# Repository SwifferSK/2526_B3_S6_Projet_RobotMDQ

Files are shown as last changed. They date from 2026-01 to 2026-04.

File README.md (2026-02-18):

<!-- ===================================================== -->
<!--                        HERO                            -->
<!-- ===================================================== -->

<p align="center">
  
</p>

<p align="center">
  
</p>

<!-- ===================================================== -->
<!--                       BADGES                           -->
<!-- ===================================================== -->

<p align="center">
  <a href="https://discord.gg/eySWAjkd">
    
  </a>

  <a href="https://www.youtube.com">
    
  </a>
</p>

<p align="center">
  

  <a href="https://www.kicad.org">
    
  </a>

  

  <a href="https://www.raspberrypi.com">
    
  </a>
</p>

---
## 🧭 Menu
- [Présentation](#présentation)
- [Fonctionnalités](#fonctionnalités)
- [Structure du dépôt](#structure-du-dépôt-branches)
- [Architecture](#architecture)
- [Hardware](#hardware)
- [Dashboard](#dashboard)
- [Demo](#demo)
- [Équipe](#équipe)

---

## Présentation

Ce projet consiste à concevoir un **robot autonome bipède** capable de suivre une ligne tracée au sol.        

Le robot utilise ses **capteurs** pour comprendre sa position et ajuste en permanence ses **moteurs** afin de ne pas tomber pendant le déplacement.

L’ensemble du système est contrôlé par une **Raspberry Pi Zero 2W**, qui traite les informations et prend les décisions en temps réel.

---

## Fonctionnalités
<div align="center">
  <table align="center" cellspacing="0" cellpadding="14">
    <tr>
      <td width="300" align="center" valign="top">
        <h3>🛤️ Suivi de ligne</h3>
        <p>
          Détection du trajet via des photorésistances/ligne<br/>
          Seuils + calibration<br/>
          Lecture analogique via ADC
        </p>
      </td>
      <td width="300" align="center" valign="top">
        <h3>🧠 Stabilisation </h3>
        <p>
          IMU (acc + gyro)<br/>
          Filtrage <br/>
          Donnée envoyer en I2C au MCU<br/>
        </p>
      </td>
      <td width="300" align="center" valign="top">
        <h3>⚙️ Contrôle</h3>
        <p>
          Boucle temps réel (PID prévu)<br/>
          Commande moteurs fluide<br/>
          Sécurités (tilt / cutoff)
        </p>
      </td>
    </tr>
  </table>
</div>

---
##  Structure du Dépôt (Branches)

Le projet est organisé de manière modulaire. La branche `main` contient le système complet, tandis que les branches de développement permettent de tester chaque composant indépendamment :

* **`main`** : Schéma électrique complet,
* **`Kicad_RPI_IMU`** :Schéma électrique de l'**IMU LSM6DSOX**.
* **`Kicad_MCP3208`** : Schéma électrique du **MCP3208** et lecture des photorésistances pour la détection de ligne.
* **`Kicad_TMC2225`** : Schéma électrique de **TMC2225** pour le contrôle des moteurs pas à pas. .
* **`merged-code`** : Fusion des 3 firmwares.
* **`Firmware_MCP3208`** : Firmmware du **MCP3208**.
* **`Firmware_LSM6DSOX`** :Firmmware du l'**IMU LSM6DSOX**.
* **`Firmware_TMC2225`** : Firmmware du **TMC2225** .
---

## Architecture

<div align="center">

  <tr>
    <td width="540" valign="top">
      <h3 align="center">🔌 Chaîne matérielle</h3>
      <p align="center">
        Capteurs optiques → <b>MCP3208 (ADC)</b><br/>
        IMU → <b>I2C/SPI</b> → <b>Raspberry Pi Zero 2W</b><br/>
        RPi → <b>GPIO</b> → <b>TMC2225</b> → Moteurs pas à pas
      </p>
    </td>
    <td width="540" valign="top">
      <h3 align="center">🧠 Chaîne de contrôle</h3>
      <p align="center">
        Acquisition → Filtrage → Estimation<br/>
        Contrôle (PID) → Commande moteurs<br/>
      </p>
    </td>
  </tr>

</div>

---

## Hardware

<div align="center">

<table align="center">
  <tr>
    <th align="left">Composant</th>
    <th align="left">Rôle</th>
    <th align="left">Interface</th>
  </tr>
  <tr>
    <td><b>Raspberry Pi Zero 2W</b></td>
    <td>Contrôleur principal</td>
    <td>GPIO / SPI / I2C</td>
  </tr>
  <tr>
    <td><b>LSM6DSOX</b></td>
    <td>IMU (acc + gyro)</td>
    <td>I2C / SPI</td>
  </tr>
  <tr>
    <td><b>MCP3208</b></td>
    <td>Convertisseur ADC</td>
    <td>SPI</td>
  </tr>
  <tr>
    <td><b>TMC2225 (x2)</b></td>
    <td>Drivers moteurs pas à pas</td>
    <td>STEP / DIR</td>
  </tr>
  <tr>
    <td><b>Capteurs optiques</b></td>
    <td>Détection de ligne</td>
    <td>Analogique</td>
  </tr>
</table>

</div>

---

## Dashboard
<div align="center">

<p align="center">
  <a href="https://github.com/SwifferSK/2526_B3_S6_Projet_RobotMDQ/issues">
    
  </a>
  <a href="https://github.com/SwifferSK/2526_B3_S6_Projet_RobotMDQ/commits/main">
    
  </a>
</p>

  </a>
  <a href="https://github.com/SwifferSK/2526_B3_S6_Projet_RobotMDQ/releases">
    
  </a>
  <a href="https://github.com/SwifferSK/2526_B3_S6_Projet_RobotMDQ">
    
  </a>
</p>

<table align="center">
  <tr>
    <td align="center" width="520">
      RepoBeats
    </td>
   
  </tr>
</table>

</div>

---

## Demo

<p align="center">
  
</p>

<p align="center">
  <!-- <img src="assets/demo.gif" width="820" alt="Demo" /> -->
</p>

---

## Équipe

<p align="center">
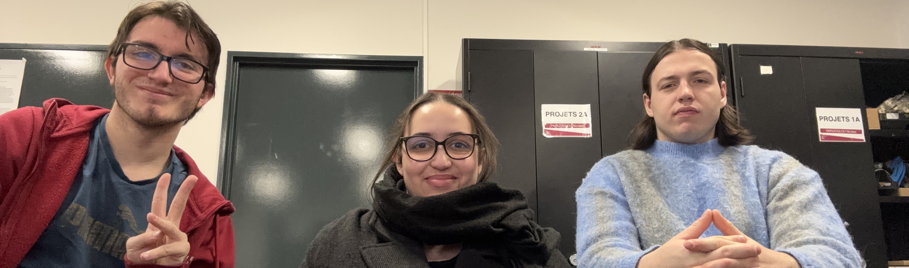
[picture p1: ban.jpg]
  
</p>
<p align="center">
  <b> Damien Theas • Manel Benboujemaa  • Quentin Bechler</b><br/>
  <sub>Bachelor ENSEA — Robotique • Design matériel</sub>
</p>

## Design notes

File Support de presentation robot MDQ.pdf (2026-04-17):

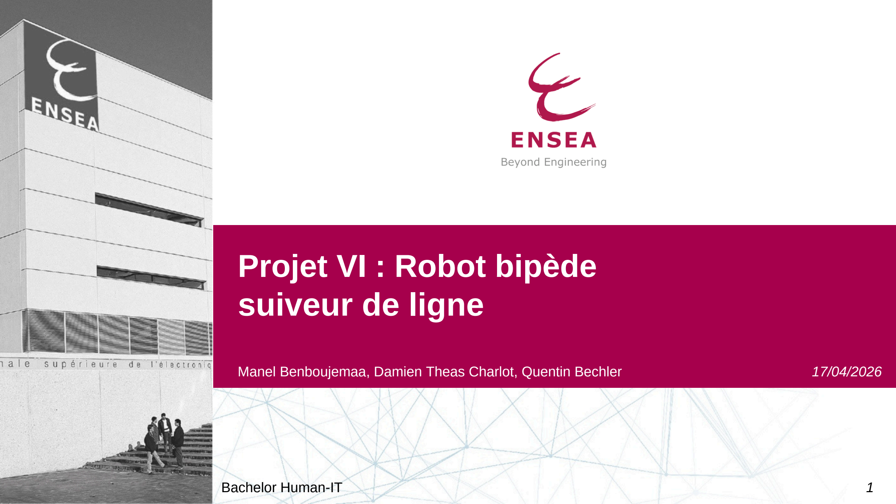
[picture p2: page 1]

# Projet VI : Robot bipède

# suiveur de ligne

Manel Benboujemaa, Damien Theas Charlot, Quentin Bechler | 17/04/2026
Bachelor Human-IT | 1

# Sommaire

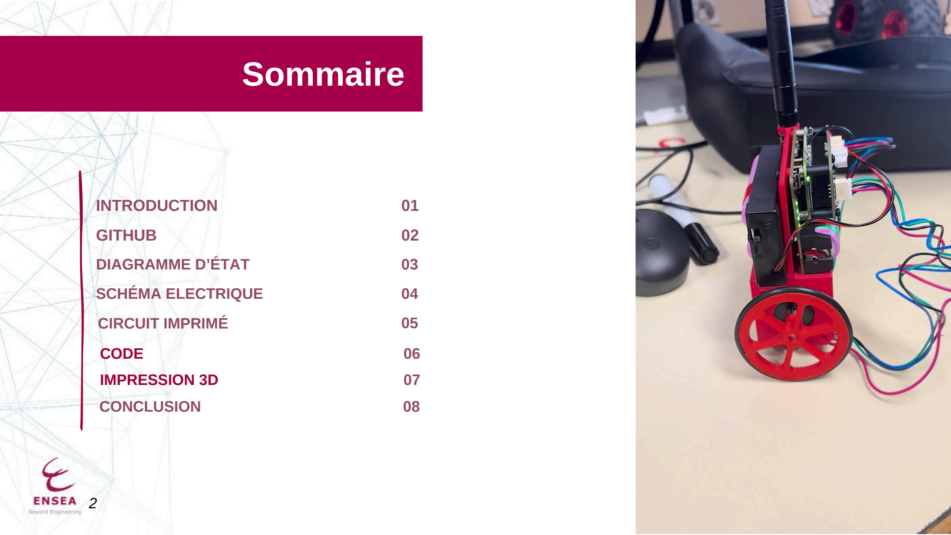
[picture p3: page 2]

INTRODUCTION
GITHUB

DIAGRAMME D’ÉTAT

CIRCUIT IMPRIMÉ

CONCLUSION

01
02

03
04

08

05

CODE

SCHÉMA ELECTRIQUE

06
IMPRESSION 3D | 07

# Introduction

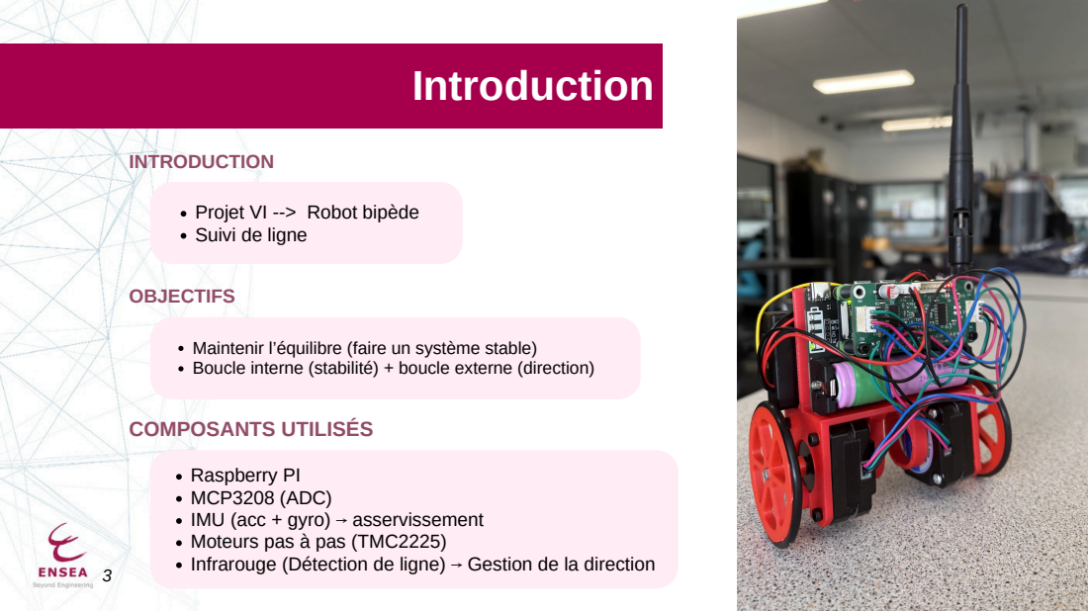
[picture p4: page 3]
INTRODUCTION; OBJECTIFS; COMPOSANTS UTILISÉS

Projet VI --> Robot bipède
Suivi de ligne

Maintenir l’équilibre (faire un système stable)
Boucle interne (stabilité) + boucle externe (direction)

Raspberry PI
MCP3208 (ADC)
IMU (acc + gyro) ⟶ asservissement
Moteurs pas à pas (TMC2225)
Infrarouge (Détection de ligne) ⟶ Gestion de la direction

# GitHub

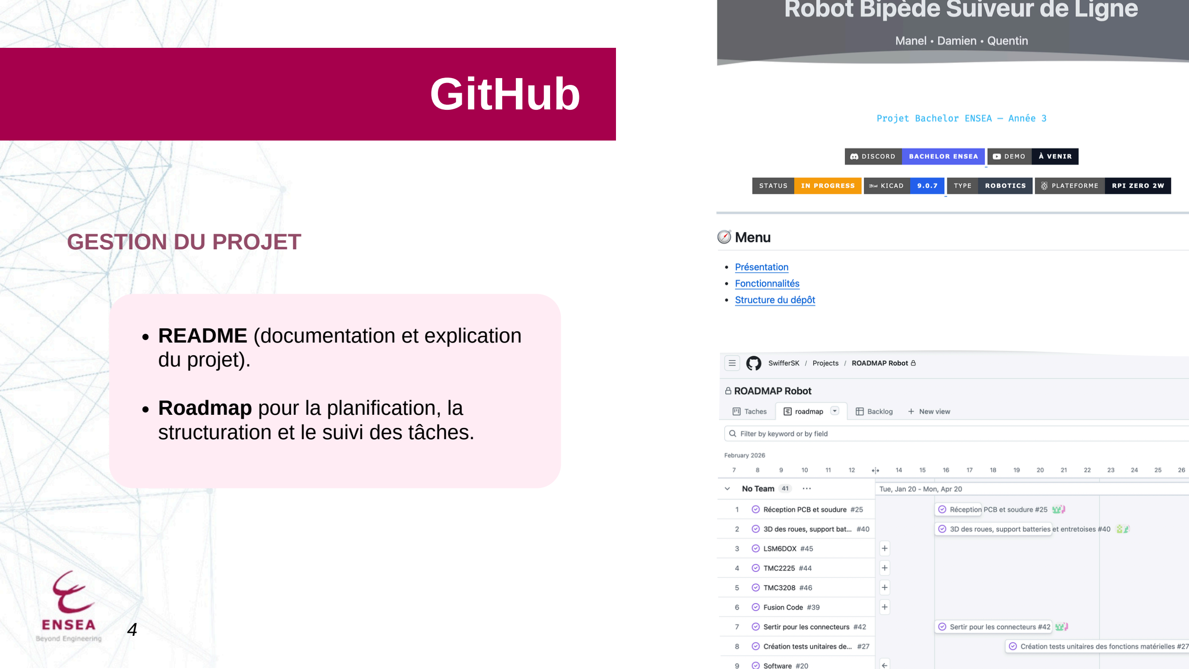
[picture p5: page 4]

README (documentation et explication du projet).

Roadmap pour la planification, la structuration et le suivi des tâches.

### GESTION DU PROJET

# Diagramme d’état

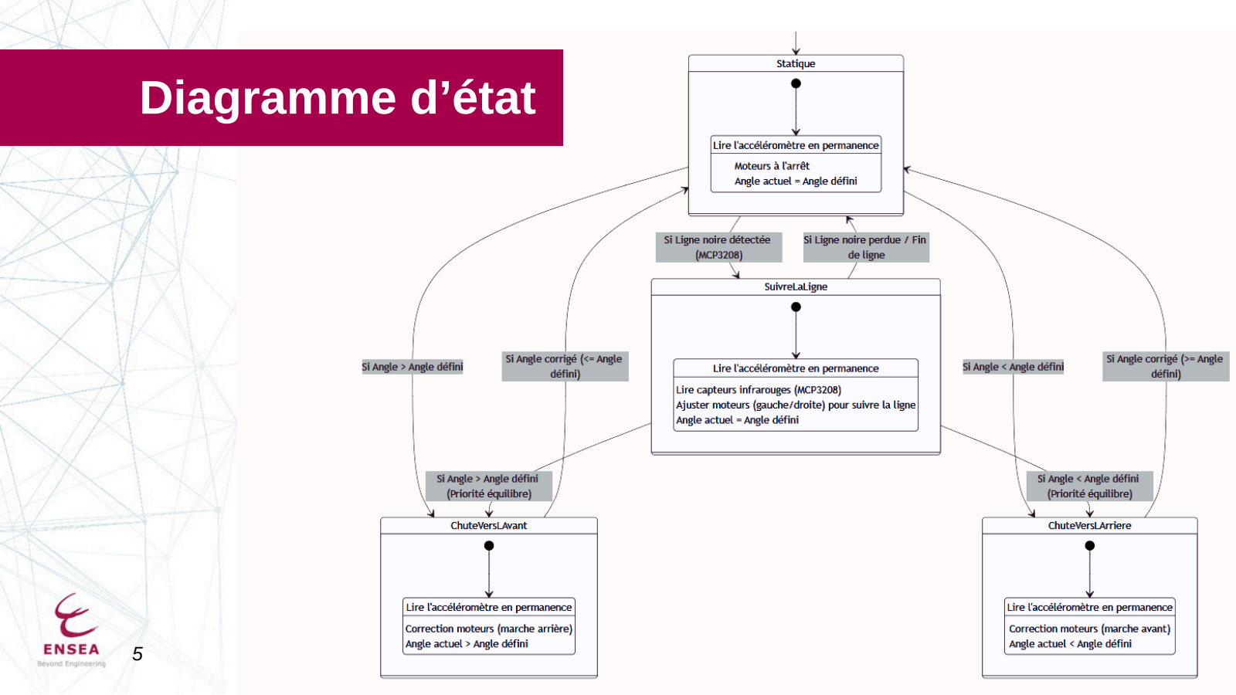
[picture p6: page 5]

# Schéma électrique

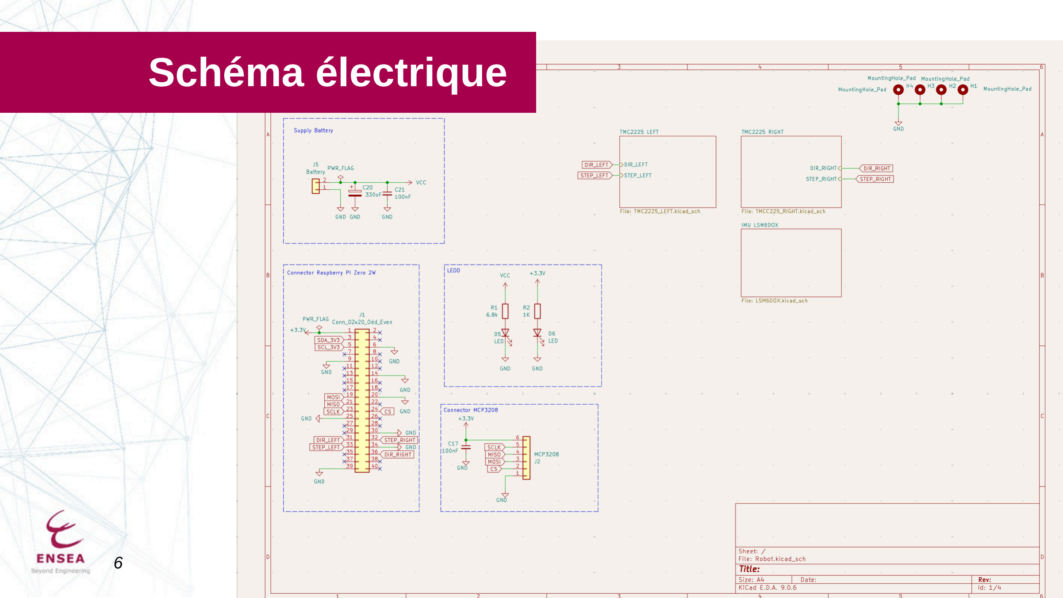
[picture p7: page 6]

# Schéma électrique

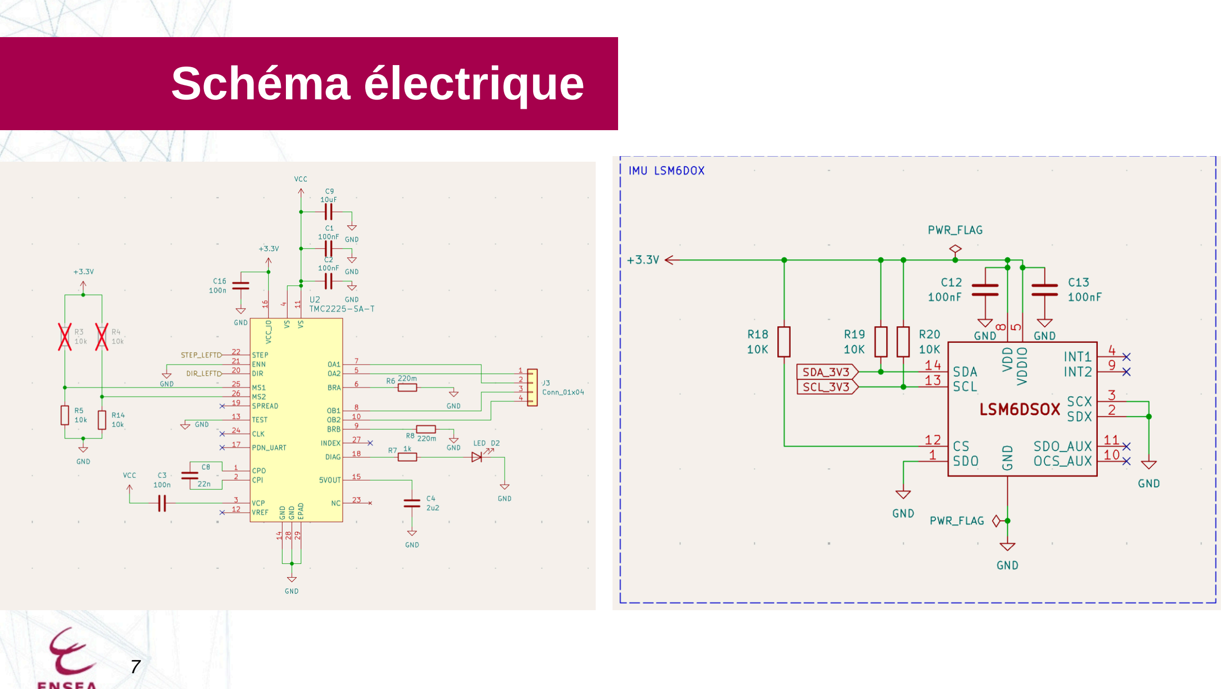
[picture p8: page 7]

# Circuit imprimé (PCB)

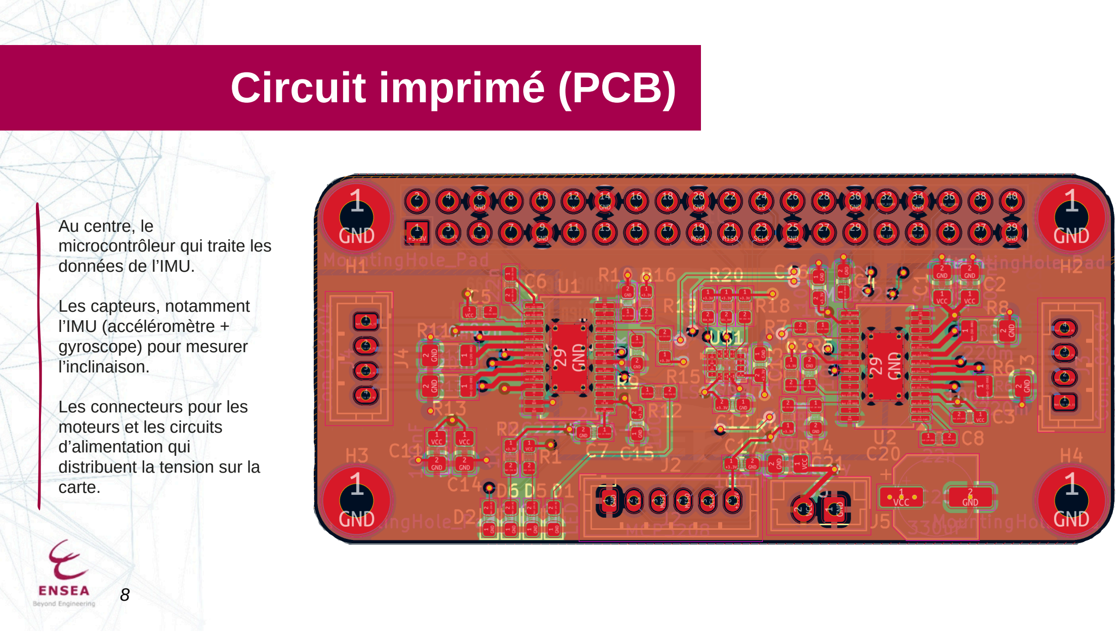
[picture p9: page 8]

Au centre, le
microcontrôleur qui traite les données de l’IMU.

Les capteurs, notamment
l’IMU (accéléromètre +
gyroscope) pour mesurer
l’inclinaison.

Les connecteurs pour les
moteurs et les circuits
d’alimentation qui
distribuent la tension sur la carte.

# Code

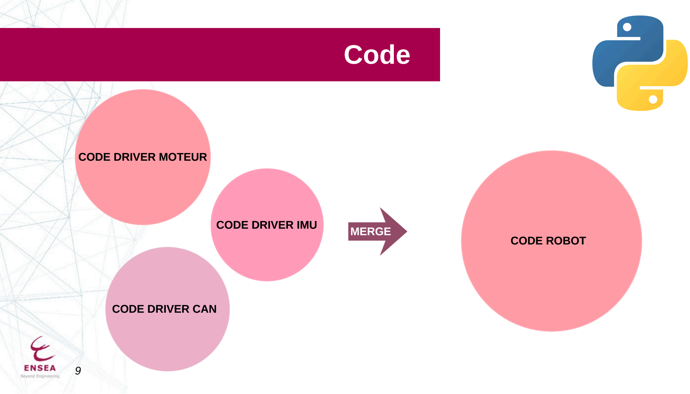
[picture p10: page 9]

CODE DRIVER MOTEUR

CODE DRIVER IMU

CODE DRIVER CAN

CODE ROBOT

MERGE

o

d

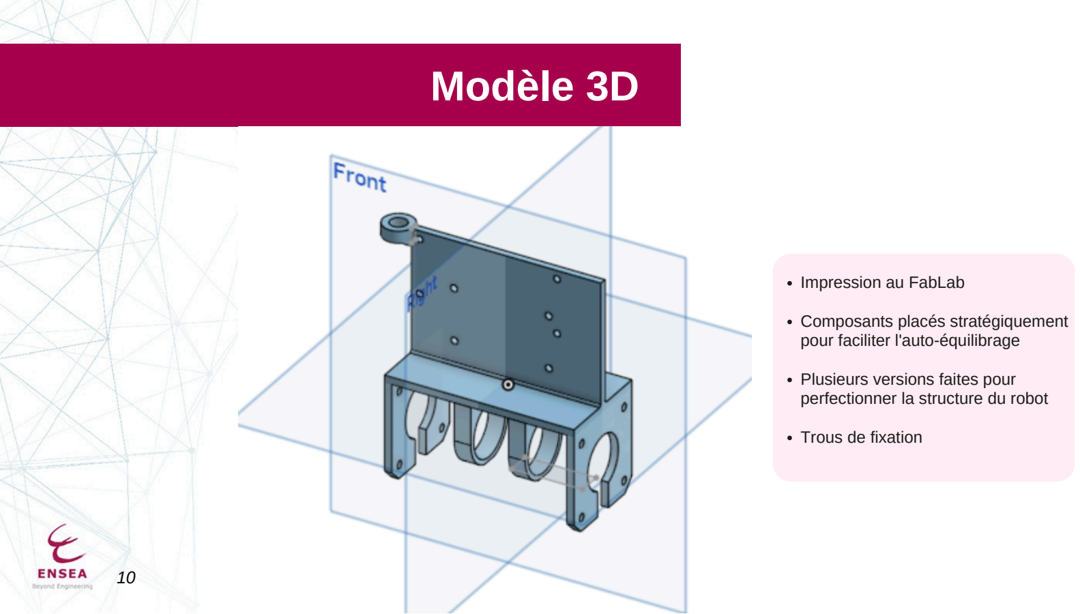
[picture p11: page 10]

10 | M

è

l

e

3

D Impressio

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
cilit

e

r l'a

u

t

o

é

q

uilib

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
r la

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
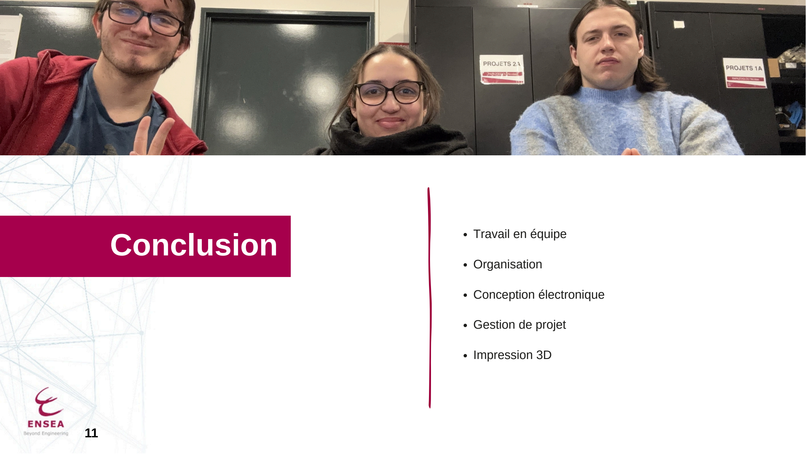
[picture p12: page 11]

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
ail e

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
t Impression 3D

1

1

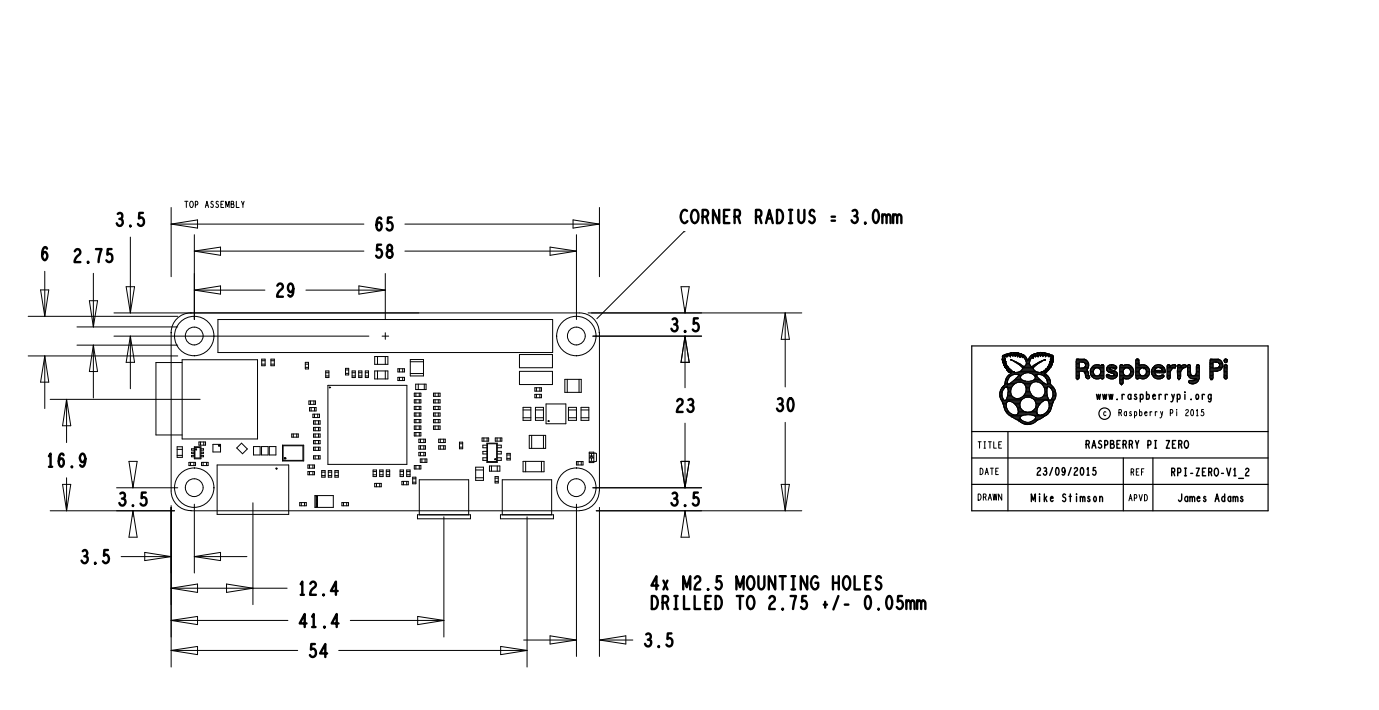
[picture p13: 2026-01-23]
Datasheets/drawings_raspberrypi.PNG

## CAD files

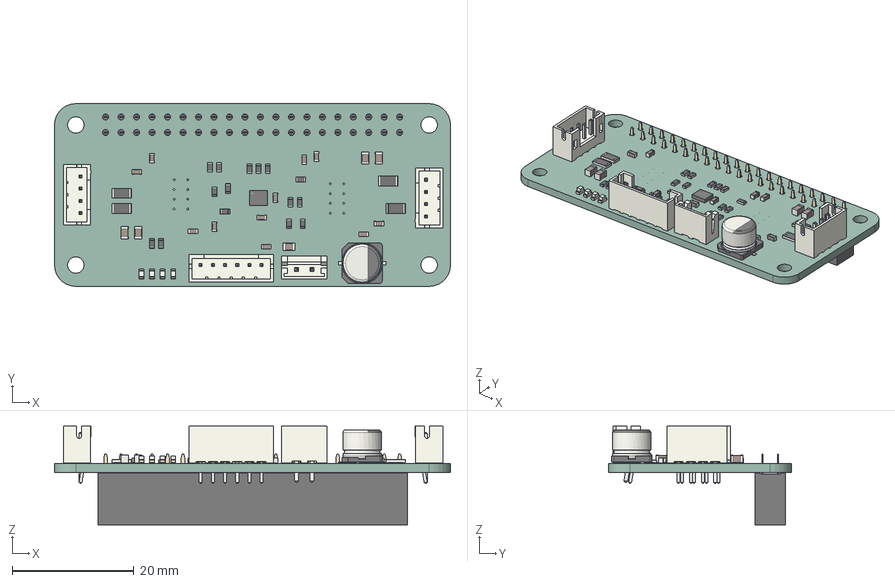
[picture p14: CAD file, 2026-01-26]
ROBOT/3D/Robot.step
65.0 x 30.0 x 16.2 mm
C_0805_2012Metric x 5
JST_PH_B4B-PH-K_1x04_P2.00mm_Vertical x 2
R_0603_1608Metric x 15
C_0603_1608Metric x 11
R_1206_3216Metric x 4
LED_0603_1608Metric x 4
JST_EH_B2B-EH-A_1x02_P2.50mm_Vertical
JST_PH_B6B-PH-K_1x06_P2.00mm_Vertical
CP_Elec_6.3x5.4
LGA-14_3x2.5mm_P0.5mm_LayoutBorder3x4y
PinSocket_2x20_P2.54mm_Vertical
Robot_PCB

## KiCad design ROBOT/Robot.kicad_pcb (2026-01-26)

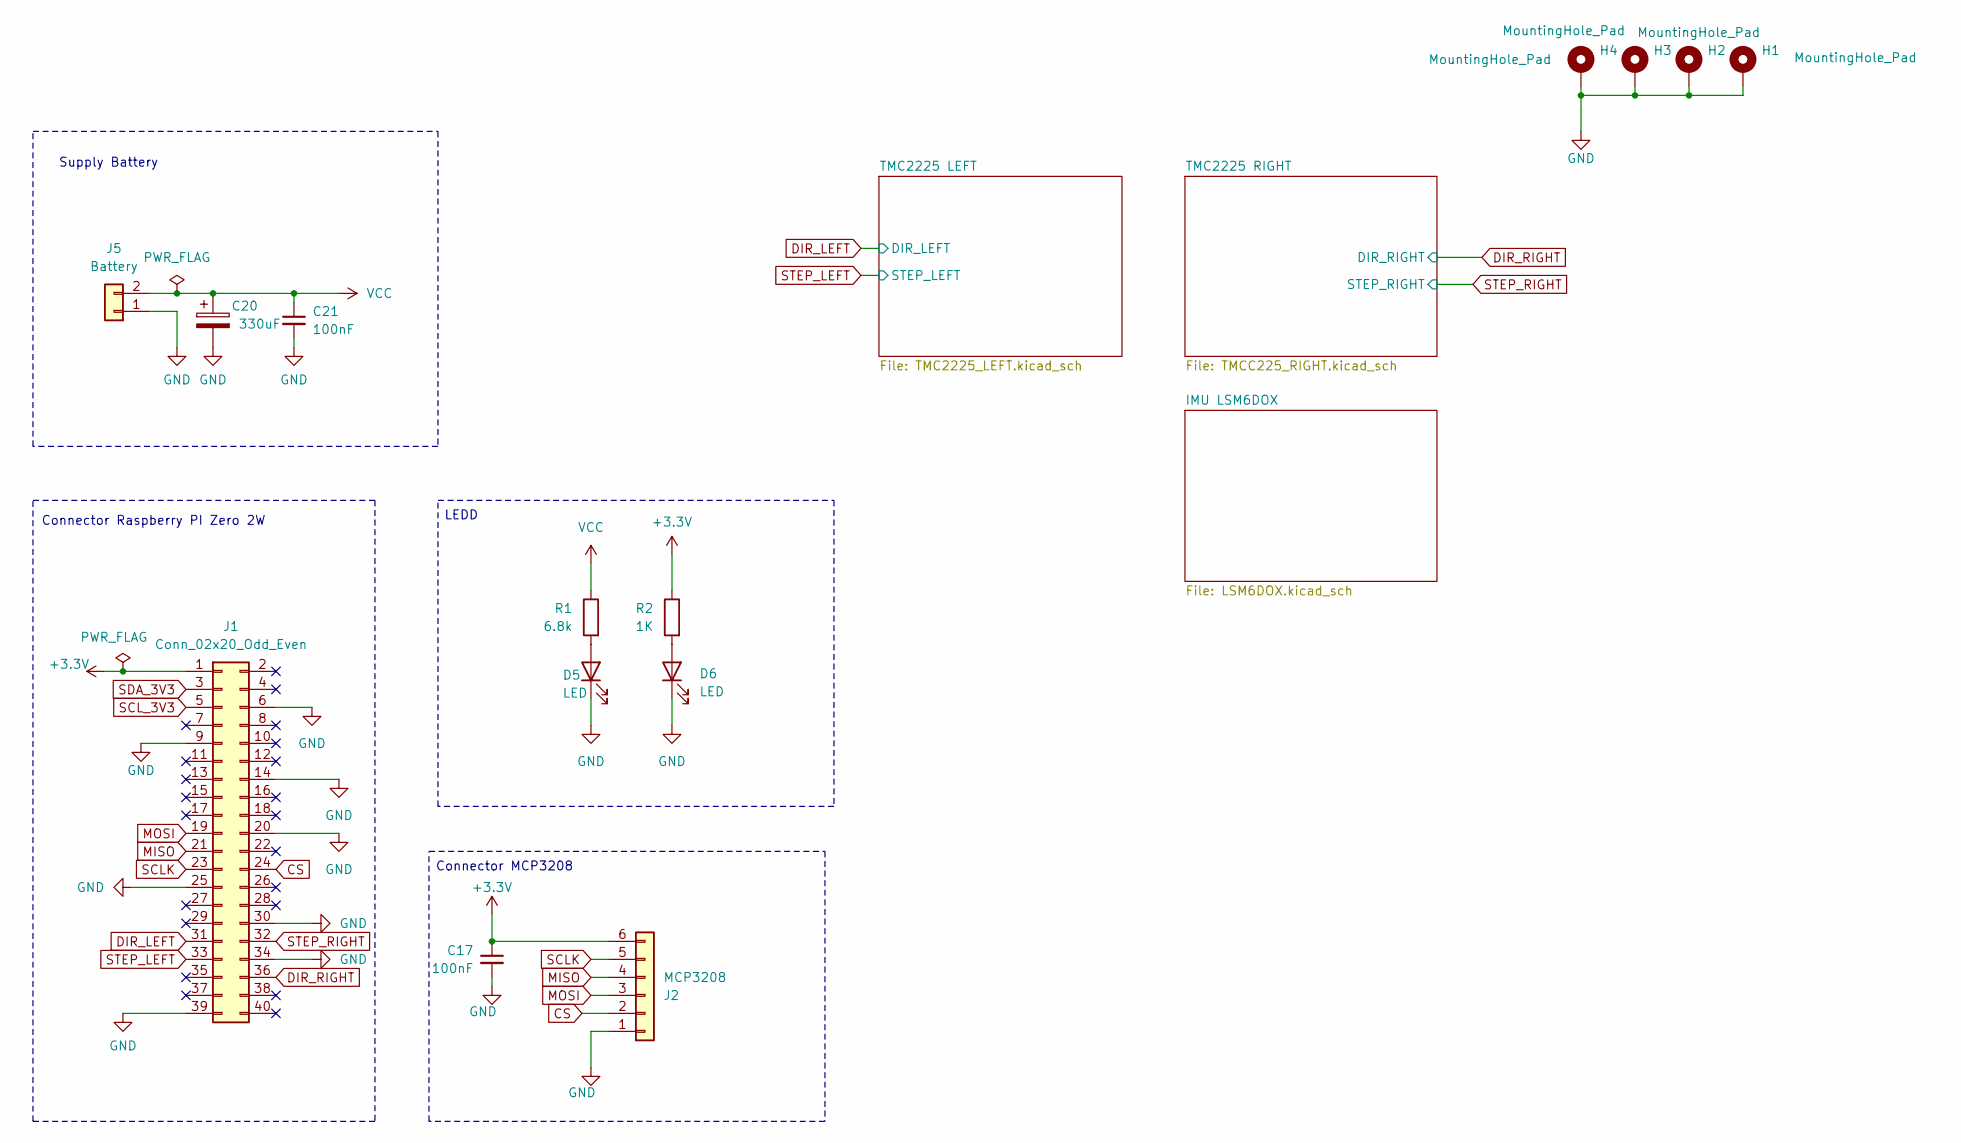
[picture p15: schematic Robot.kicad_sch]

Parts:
C17: 100nF; C_0603_1608Metric_Pad1.08x0.95mm_HandSolder
C20: 330uF; CP_Elec_6.3x5.4
C21: 100nF; C_0805_2012Metric_Pad1.18x1.45mm_HandSolder
D5, D6: LED; LED_0603_1608Metric_Pad1.05x0.95mm_HandSolder
H1, H2, H3, H4: MountingHole_Pad; MountingHole_2.7mm_M2.5_Pad
J1: Conn_02x20_Odd_Even; PinSocket_2x20_P2.54mm_Vertical
J2: MCP3208; JST_PH_B6B-PH-K_1x06_P2.00mm_Vertical
J5: Battery; JST_EH_B2B-EH-A_1x02_P2.50mm_Vertical
R1: 6.8k; R_0603_1608Metric_Pad0.98x0.95mm_HandSolder
R2: 1K; R_0603_1608Metric_Pad0.98x0.95mm_HandSolder

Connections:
+3.3V: C17.1, J1.1, J2.6, R2.1; also elsewhere on the board
CS: J1.24, J2.2
DIR_LEFT: J1.31; also elsewhere on the board
DIR_RIGHT: J1.36; also elsewhere on the board
GND: C17.2, C20.2, C21.2, D5.1 (K), D6.1 (K), H1.1, H2.1, H3.1, H4.1, J1.6, J1.9, J1.14, J1.20, J1.25, J1.30, J1.34, J1.39, J2.1, J5.1; also elsewhere on the board
MISO: J1.21, J2.4
MOSI: J1.19, J2.3
unnamed: D5.2 (A), R1.2
unnamed: D6.2 (A), R2.2
SCLK: J1.23, J2.5
SCL_3V3: J1.5; also elsewhere on the board
SDA_3V3: J1.3; also elsewhere on the board
STEP_LEFT: J1.33; also elsewhere on the board
STEP_RIGHT: J1.32; also elsewhere on the board
VCC: C20.1, C21.1, J5.2, R1.1; also elsewhere on the board

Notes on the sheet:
Supply Battery
Connector MCP3208
Connector Raspberry PI Zero 2W
LEDD

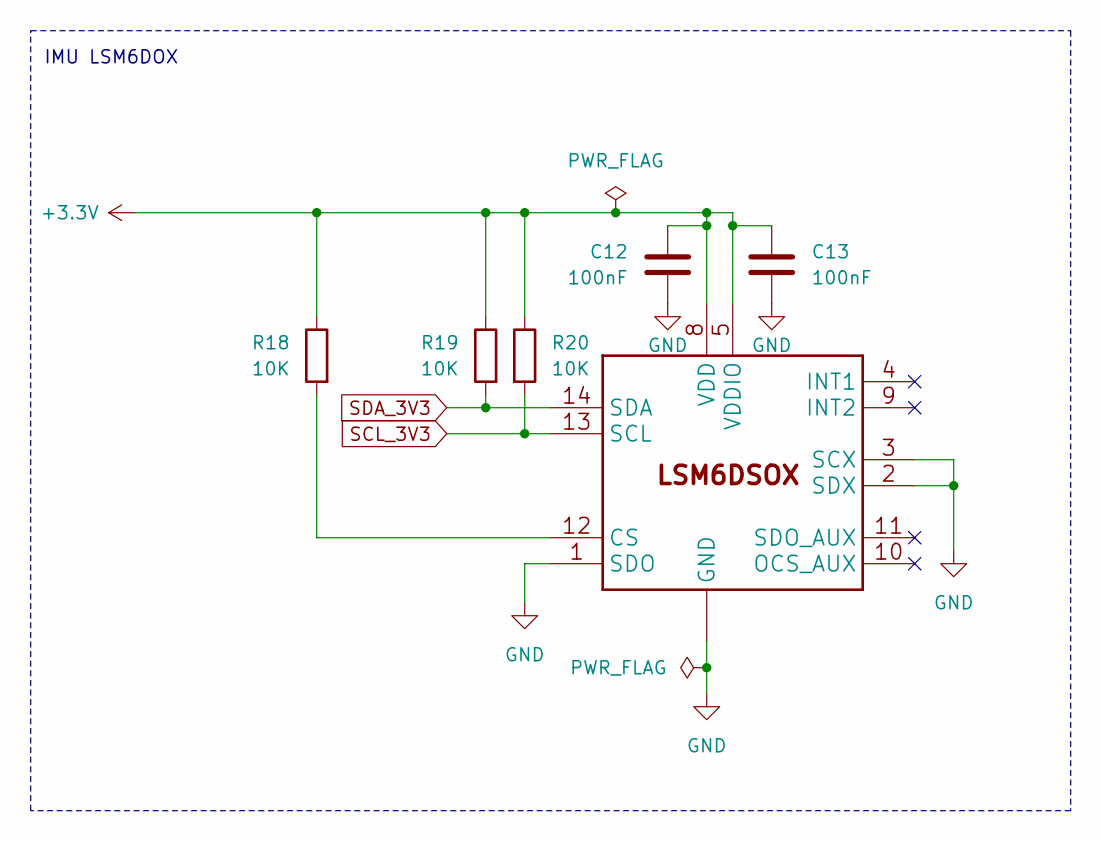
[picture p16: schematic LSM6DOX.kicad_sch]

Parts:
C12, C13: 100nF; C_0603_1608Metric_Pad1.08x0.95mm_HandSolder
R18, R19, R20: 10K; R_0603_1608Metric_Pad0.98x0.95mm_HandSolder
U$1: LSM6DSOX; LGA-14_3x2.5mm_P0.5mm_LayoutBorder3x4y

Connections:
+3.3V: C12.2, C13.2, R18.1, R19.1, R20.1, U$1.5 (VDDIO), U$1.8 (VDD); also elsewhere on the board
GND: C12.1, C13.1, U$1.1 (SDO), U$1.2 (SDX), U$1.3 (SCX), U$1.6 (GND), U$1.7 (GND); also elsewhere on the board
unnamed: R18.2, U$1.12 (CS)
SCL_3V3: R20.2, U$1.13 (SCL); also elsewhere on the board
SDA_3V3: R19.2, U$1.14 (SDA); also elsewhere on the board

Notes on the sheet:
IMU LSM6DOX

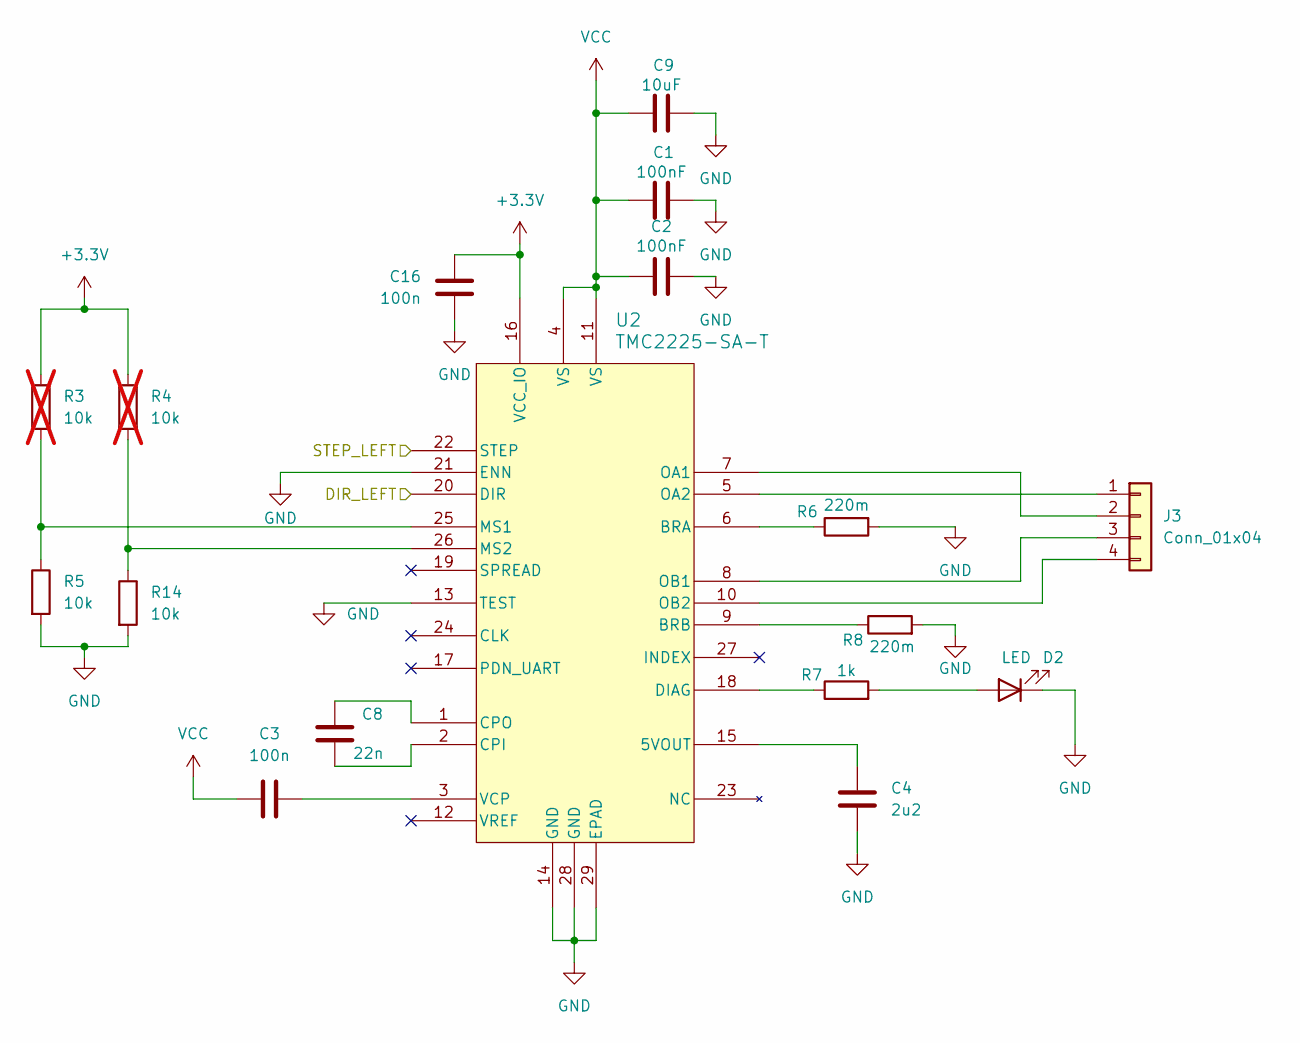
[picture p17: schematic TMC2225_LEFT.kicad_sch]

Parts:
C1, C2: 100nF; C_0603_1608Metric_Pad1.08x0.95mm_HandSolder
C3, C16: 100n; C_0603_1608Metric_Pad1.08x0.95mm_HandSolder
C4: 2u2; C_0603_1608Metric_Pad1.08x0.95mm_HandSolder
C8: 22n; C_0603_1608Metric_Pad1.08x0.95mm_HandSolder
C9: 10uF; C_0805_2012Metric_Pad1.18x1.45mm_HandSolder
D2: LED; LED_0603_1608Metric_Pad1.05x0.95mm_HandSolder
J3: Conn_01x04; JST_PH_B4B-PH-K_1x04_P2.00mm_Vertical
R3, R4: 10k; R_0603_1608Metric_Pad0.98x0.95mm_HandSolder; not fitted
R5, R14: 10k; R_0603_1608Metric_Pad0.98x0.95mm_HandSolder
R6, R8: 220m; R_1206_3216Metric_Pad1.30x1.75mm_HandSolder
R7: 1k; R_0603_1608Metric_Pad0.98x0.95mm_HandSolder
U2: TMC2225-SA-T; HTSSOP-28-1EP_4.4x9.7mm_P0.65mm_EP2.85x5.4mm_ThermalVias

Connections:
+3.3V: C16.2, R3.1, R4.1, U2.16 (VCC_IO); also elsewhere on the board
DIR_LEFT: U2.20 (DIR); also elsewhere on the board
GND: C1.2, C2.2, C4.2, C9.2, C16.1, D2.1 (K), R5.2, R6.2, R8.2, R14.2, U2.13 (TEST), U2.14 (GND), U2.21 (ENN), U2.28 (GND), U2.29 (EPAD); also elsewhere on the board
unnamed: D2.2 (A), R7.2
unnamed: J3.1, U2.5 (OA2)
unnamed: J3.2, U2.7 (OA1)
unnamed: J3.3, U2.8 (OB1)
unnamed: J3.4, U2.10 (OB2)
unnamed: C4.1, U2.15 (5VOUT)
unnamed: R6.1, U2.6 (BRA)
unnamed: R8.1, U2.9 (BRB)
unnamed: C8.2, U2.2 (CPI)
unnamed: C8.1, U2.1 (CPO)
unnamed: R7.1, U2.18 (DIAG)
unnamed: R3.2, R5.1, U2.25 (MS1)
unnamed: R4.2, R14.1, U2.26 (MS2)
unnamed: C3.2, U2.3 (VCP)
STEP_LEFT: U2.22 (STEP); also elsewhere on the board
VCC: C1.1, C2.1, C3.1, C9.1, U2.4 (VS), U2.11 (VS); also elsewhere on the board

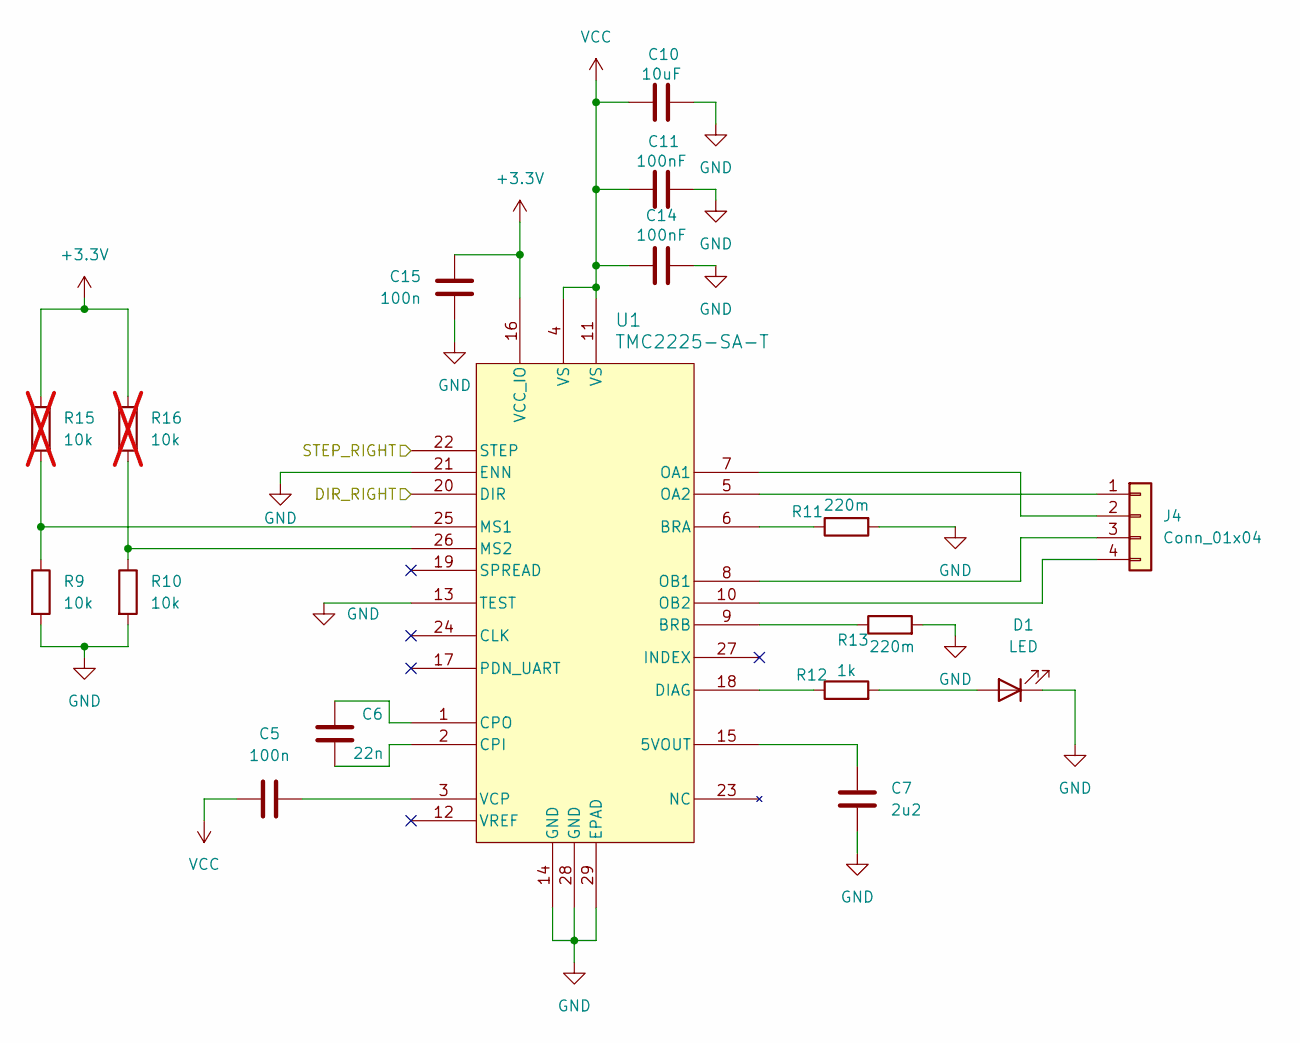
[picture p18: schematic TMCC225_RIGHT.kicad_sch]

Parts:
C5, C15: 100n; C_0603_1608Metric_Pad1.08x0.95mm_HandSolder
C6: 22n; C_0603_1608Metric_Pad1.08x0.95mm_HandSolder
C7: 2u2; C_0603_1608Metric_Pad1.08x0.95mm_HandSolder
C10: 10uF; C_0805_2012Metric_Pad1.18x1.45mm_HandSolder
C11, C14: 100nF; C_0603_1608Metric_Pad1.08x0.95mm_HandSolder
D1: LED; LED_0603_1608Metric_Pad1.05x0.95mm_HandSolder
J4: Conn_01x04; JST_PH_B4B-PH-K_1x04_P2.00mm_Vertical
R9, R10: 10k; R_0603_1608Metric_Pad0.98x0.95mm_HandSolder
R11, R13: 220m; R_1206_3216Metric_Pad1.30x1.75mm_HandSolder
R12: 1k; R_0603_1608Metric_Pad0.98x0.95mm_HandSolder
R15, R16: 10k; R_0603_1608Metric_Pad0.98x0.95mm_HandSolder; not fitted
U1: TMC2225-SA-T; HTSSOP-28-1EP_4.4x9.7mm_P0.65mm_EP2.85x5.4mm_ThermalVias

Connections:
+3.3V: C15.2, R15.1, R16.1, U1.16 (VCC_IO); also elsewhere on the board
DIR_RIGHT: U1.20 (DIR); also elsewhere on the board
GND: C7.2, C10.2, C11.2, C14.2, C15.1, D1.1 (K), R9.2, R10.2, R11.2, R13.2, U1.13 (TEST), U1.14 (GND), U1.21 (ENN), U1.28 (GND), U1.29 (EPAD); also elsewhere on the board
unnamed: D1.2 (A), R12.2
unnamed: J4.1, U1.5 (OA2)
unnamed: J4.2, U1.7 (OA1)
unnamed: J4.3, U1.8 (OB1)
unnamed: J4.4, U1.10 (OB2)
unnamed: C7.1, U1.15 (5VOUT)
unnamed: R11.1, U1.6 (BRA)
unnamed: R13.1, U1.9 (BRB)
unnamed: C6.2, U1.2 (CPI)
unnamed: C6.1, U1.1 (CPO)
unnamed: R12.1, U1.18 (DIAG)
unnamed: R9.1, R15.2, U1.25 (MS1)
unnamed: R10.1, R16.2, U1.26 (MS2)
unnamed: C5.2, U1.3 (VCP)
STEP_RIGHT: U1.22 (STEP); also elsewhere on the board
VCC: C5.1, C10.1, C11.1, C14.1, U1.4 (VS), U1.11 (VS); also elsewhere on the board

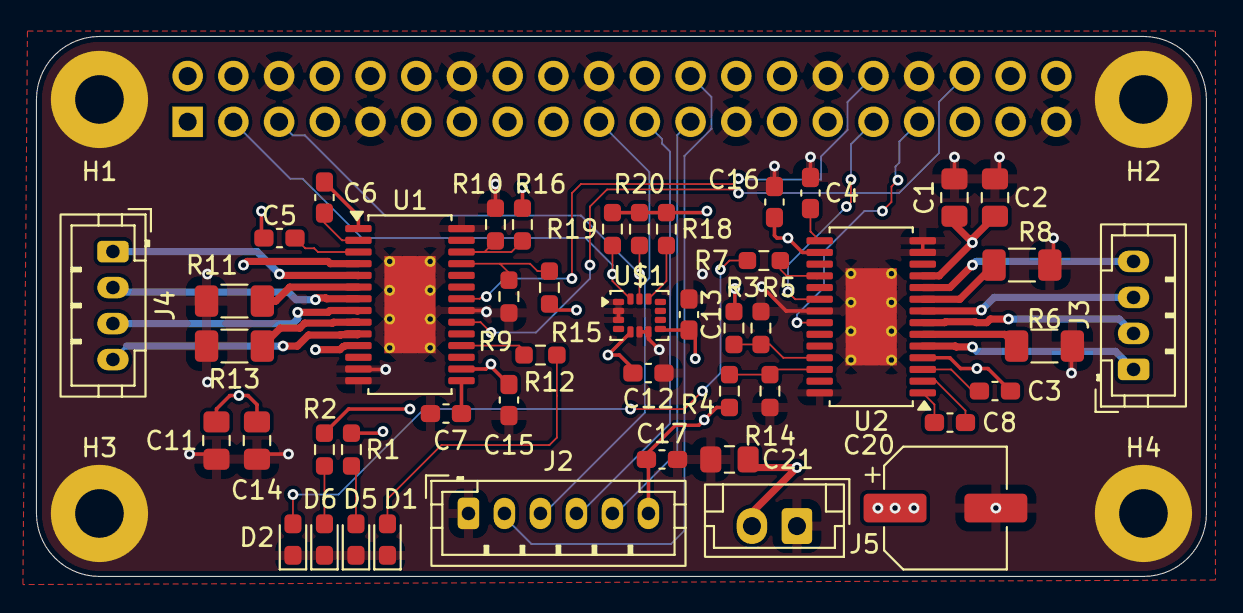
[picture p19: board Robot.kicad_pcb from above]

Board: 4 copper layers, 65.0 x 30.0 mm, 52 parts (1 on the bottom side), 44 nets.

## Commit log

2026-01-21 Schema KiCad ROBOT
    Schema KiCad ROBOT
    [Robot.kicad_pcb, Robot.kicad_sch, TMC2225_LEFT.kicad_sch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]
2026-01-21 add DC-DC BUCK + LED
    add DC-DC BUCK + LED
    [Robot.kicad_sch]
2026-01-23 correction schéma
    correction schéma
    [LSM6DOX.kicad_sch, Robot.kicad_sch, TMC2225_LEFT.kicad_sch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]
2026-01-23 add footprint
    [Robot.kicad_sch, TMC2225_LEFT.kicad_sch, TMCC225_RIGHT.kicad_sch]
2026-01-23 Schema OK
    [TMC2225_LEFT.kicad_sch, TMCC225_RIGHT.kicad_sch]
2026-01-23 edge cut cotation
    [Robot.kicad_pcb]
2026-01-23 Update PCB
    [Robot.kicad_pcb]
2026-01-24 First Routage
    [LSM6DOX.kicad_sch, Robot.kicad_pcb]
2026-01-25 Schema PCB no error
    [Robot.kicad_pcb]
2026-01-25 Update backup
    [Robot.kicad_pcb]
2026-01-25 GND PAD 29 TMC22225
    [Robot.kicad_pcb, TMC2225_LEFT.kicad_sch, TMCC225_RIGHT.kicad_sch]
2026-01-26 Update PCB routage
    [Robot.kicad_pcb]
2026-01-26 Piste puissance + via GND
2026-01-26 add datasheet in documentation
    [Robot.kicad_pcb]
2026-01-26 PCB 3D
    [Robot.step]
2026-01-26 Update netclass
    [Robot.kicad_pcb]
2026-01-26 add condo
    [TMC2225_LEFT.kicad_sch, TMCC225_RIGHT.kicad_sch]
2026-01-26 Revue de shcema
    [Robot.kicad_pcb]
2026-01-26 PCB style
    [Robot.kicad_pcb]
2026-01-26 update silkscreen
    [Robot.kicad_pcb]
2026-01-26 update MPN
    [Robot.kicad_pcb]
2026-01-26 B.silkscreen Text + Logo
    [Robot.kicad_pcb]
2026-01-26 Gerber file
    [Robot-B_Cu.gbr, Robot-B_Mask.gbr, Robot-B_Paste.gbr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]
2026-01-26 Update B.silkscreen text + logo
    [Robot.kicad_pcb]
2026-02-17 Revise project overview and add repository structure
    Updated project description and features in README.md. Added repository structure and clarified sensor descriptions.
